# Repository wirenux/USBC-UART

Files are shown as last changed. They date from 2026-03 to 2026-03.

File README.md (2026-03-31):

# USB-C to UART Bridge

A simple project to convert a traditional USB-B UART bridge schematic to a modern **USB-C** interface.

---

## PCB & 3D

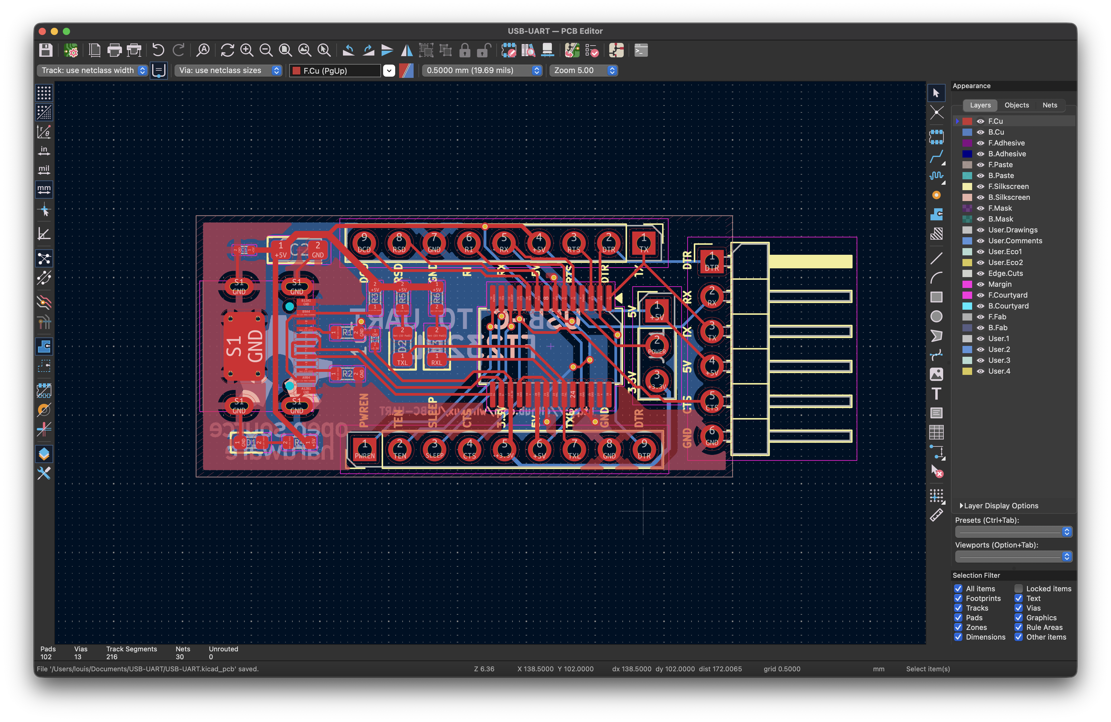
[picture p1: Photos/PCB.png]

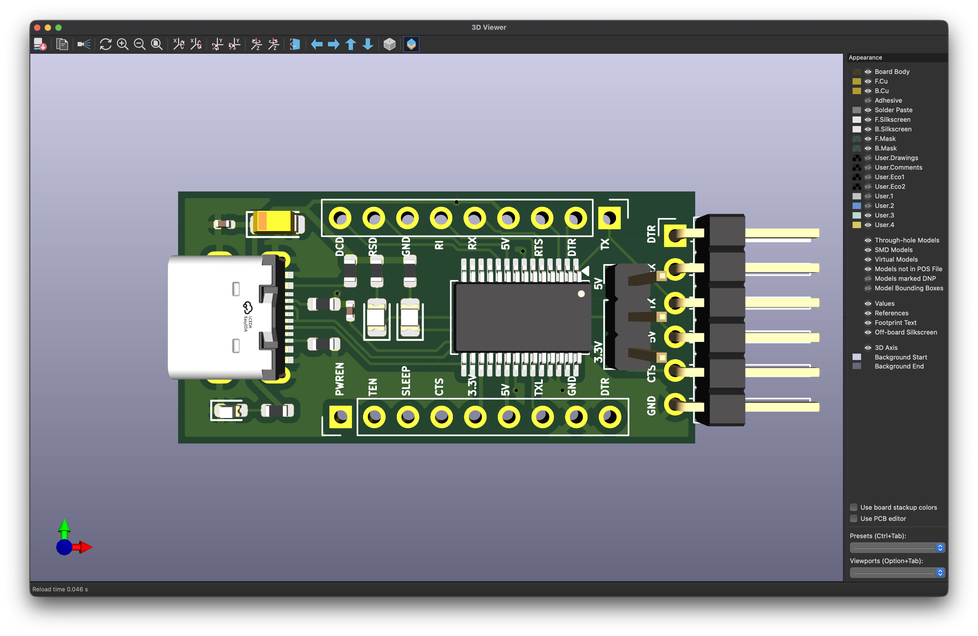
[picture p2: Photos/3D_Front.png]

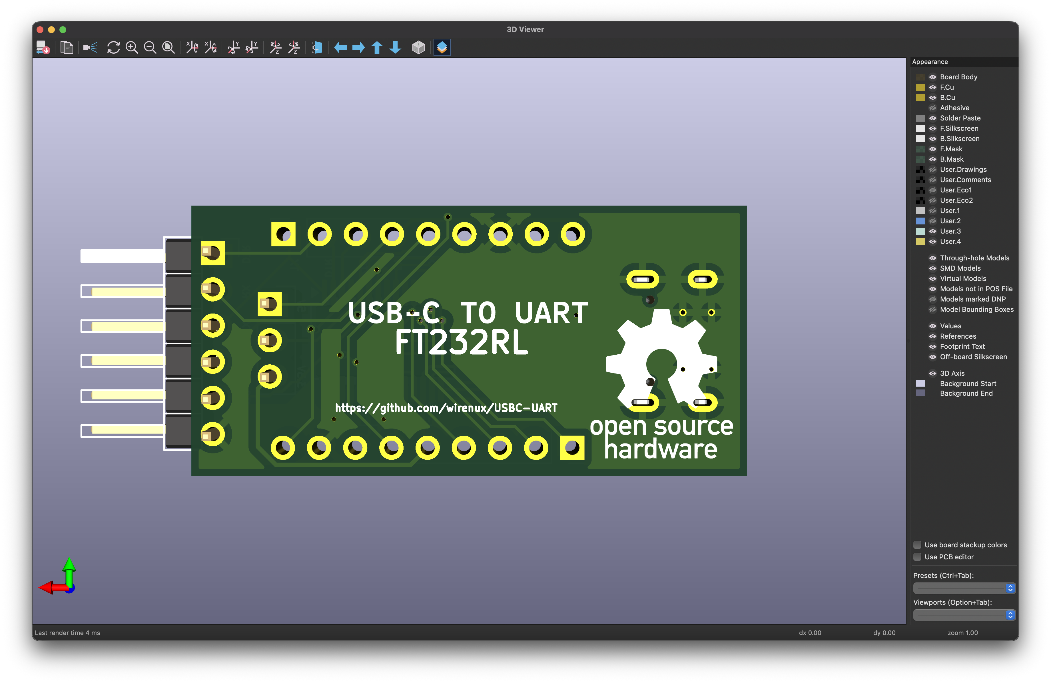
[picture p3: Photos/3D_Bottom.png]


## CC Resistors

For the device to work with **USB-C to USB-C cables**, you must add two resistors to the configuration pins:

* **CC1 (Pin A5):** Connect a **5.1kΩ** resistor to **GND**.
* **CC2 (Pin B5):** Connect a **5.1kΩ** resistor to **GND**.

---

## Schematic

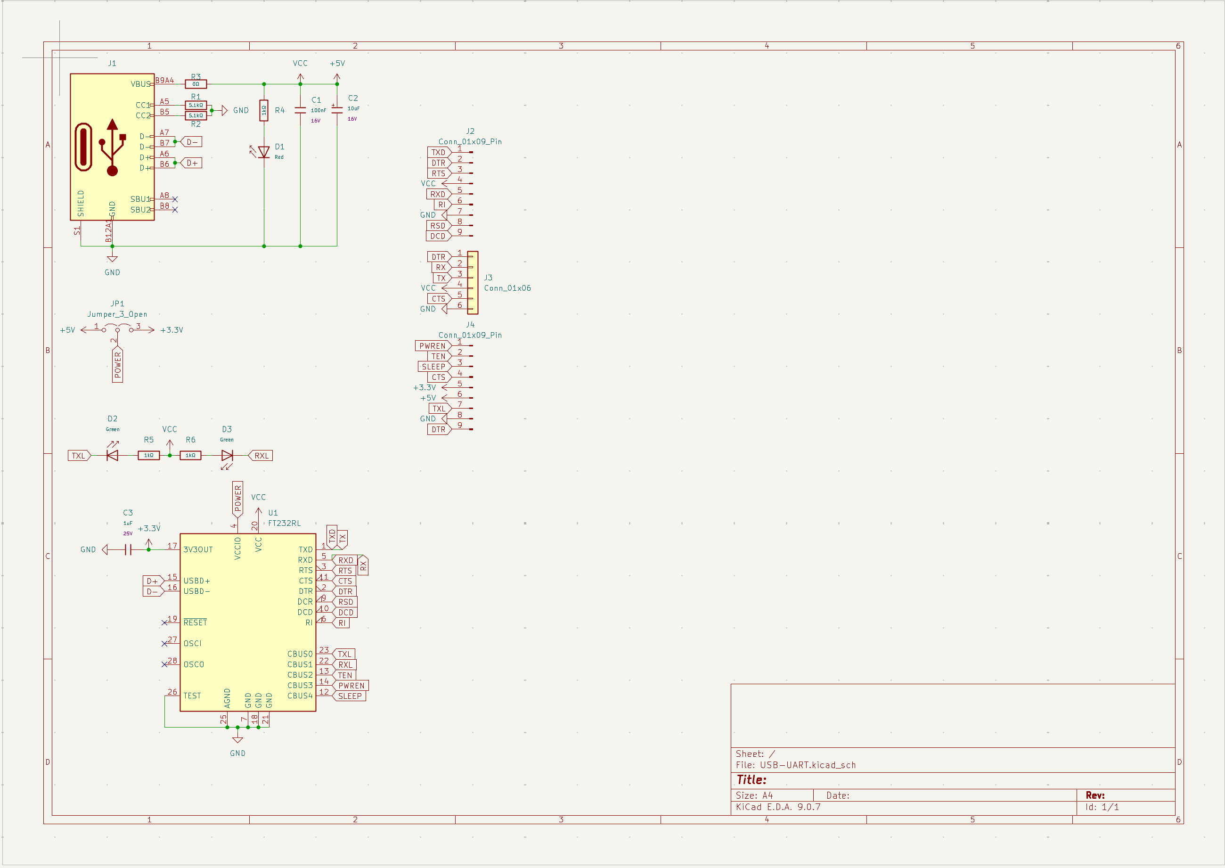
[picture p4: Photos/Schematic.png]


---

## License

This project is under [MIT](./LICENSE) license.

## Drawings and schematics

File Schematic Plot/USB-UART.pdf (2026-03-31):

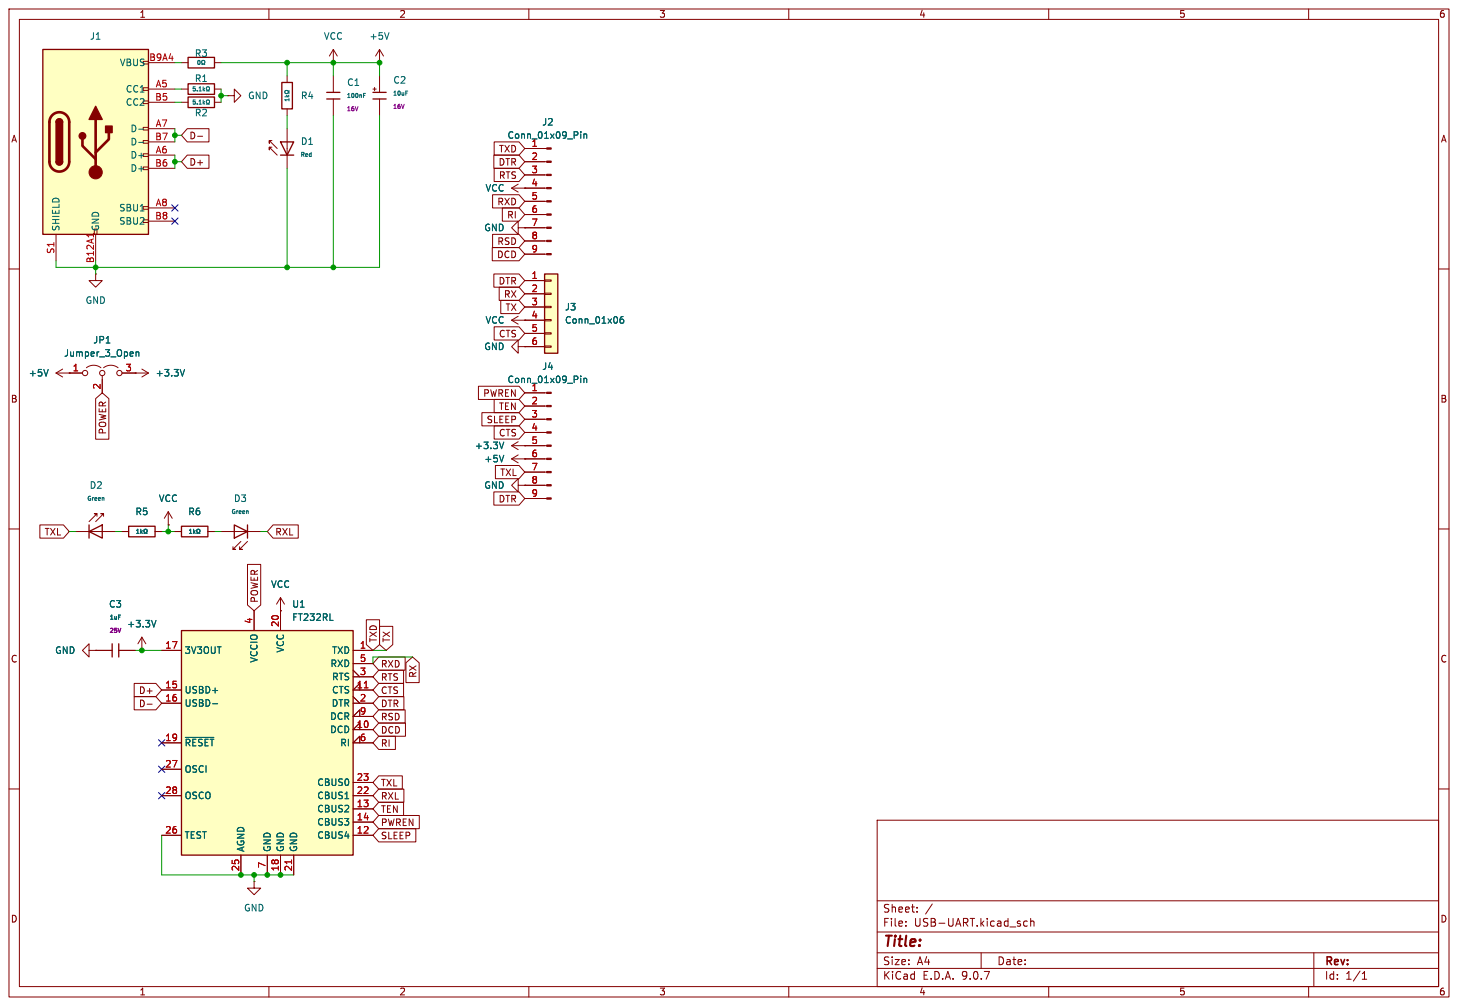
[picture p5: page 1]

Id: 1/1 Title: File: USB-UART.kicad_sch Sheet: / D2

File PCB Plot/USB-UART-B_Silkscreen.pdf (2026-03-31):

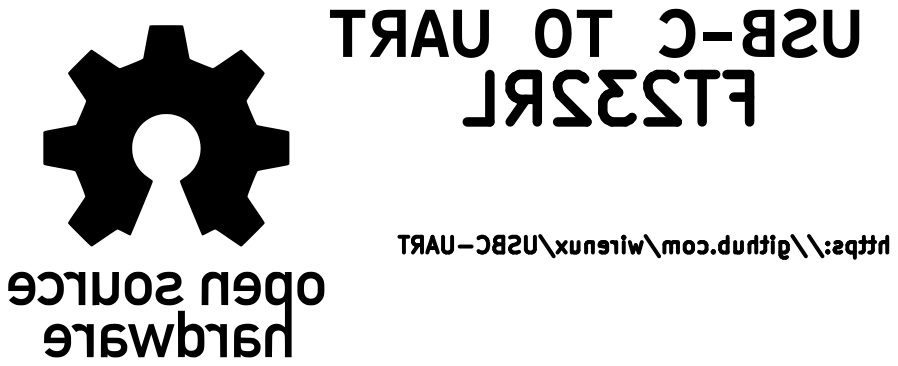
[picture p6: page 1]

https://github.com/wirenux/USBC-UART FT232RL

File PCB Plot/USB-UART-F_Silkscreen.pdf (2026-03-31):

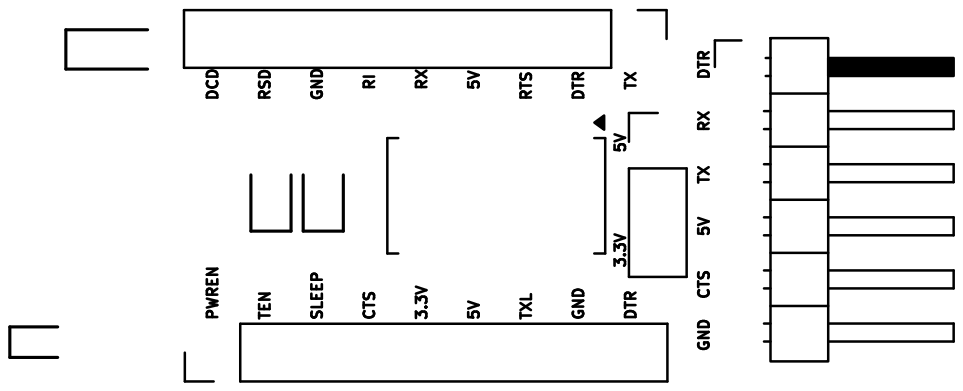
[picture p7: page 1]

5V DCD RTSDTR RX TXL TX DTR RX 5V SLEEP CTS 5V DTRTX CTS 3.3V 3.3V GND GNDPWREN TEN RI 5V RSD GND

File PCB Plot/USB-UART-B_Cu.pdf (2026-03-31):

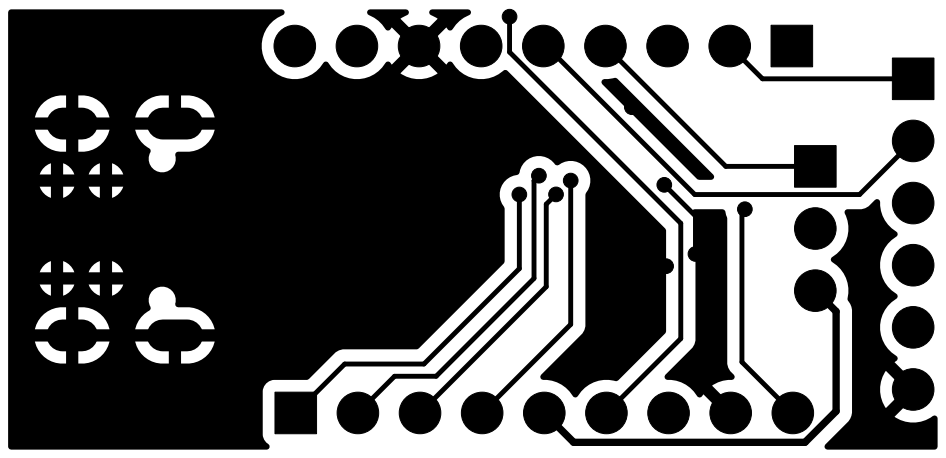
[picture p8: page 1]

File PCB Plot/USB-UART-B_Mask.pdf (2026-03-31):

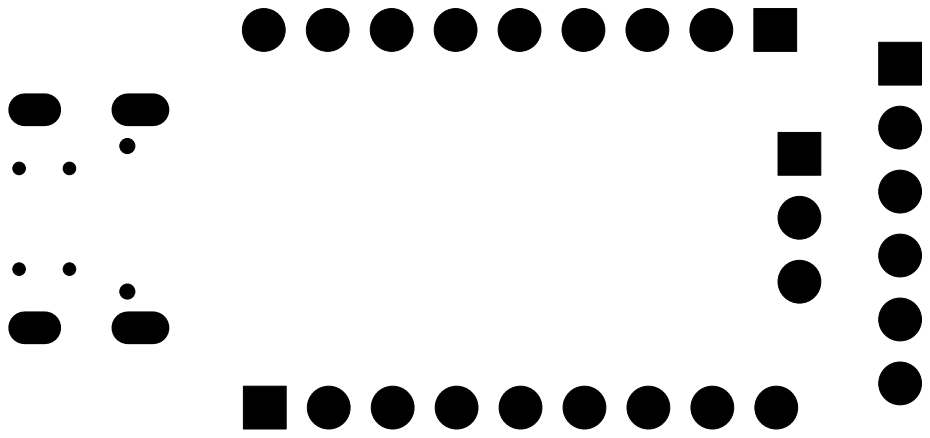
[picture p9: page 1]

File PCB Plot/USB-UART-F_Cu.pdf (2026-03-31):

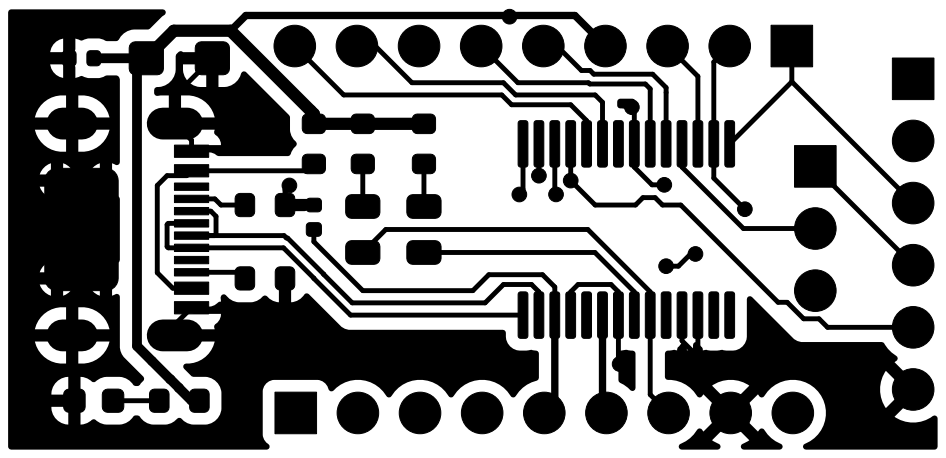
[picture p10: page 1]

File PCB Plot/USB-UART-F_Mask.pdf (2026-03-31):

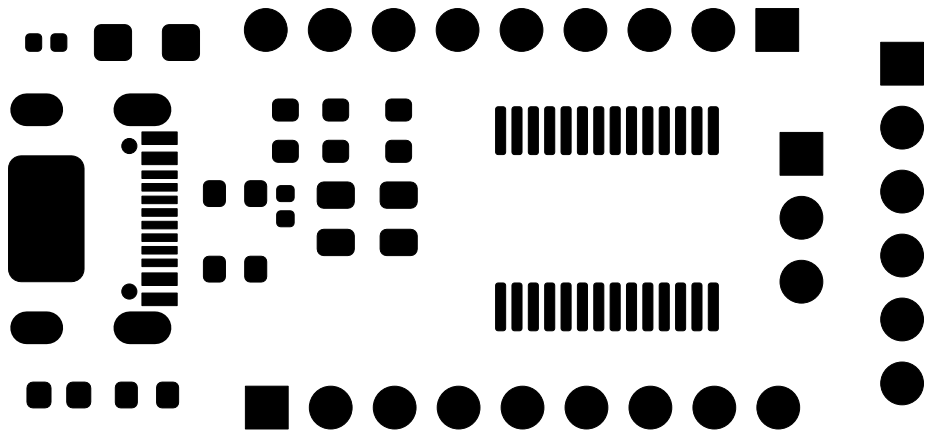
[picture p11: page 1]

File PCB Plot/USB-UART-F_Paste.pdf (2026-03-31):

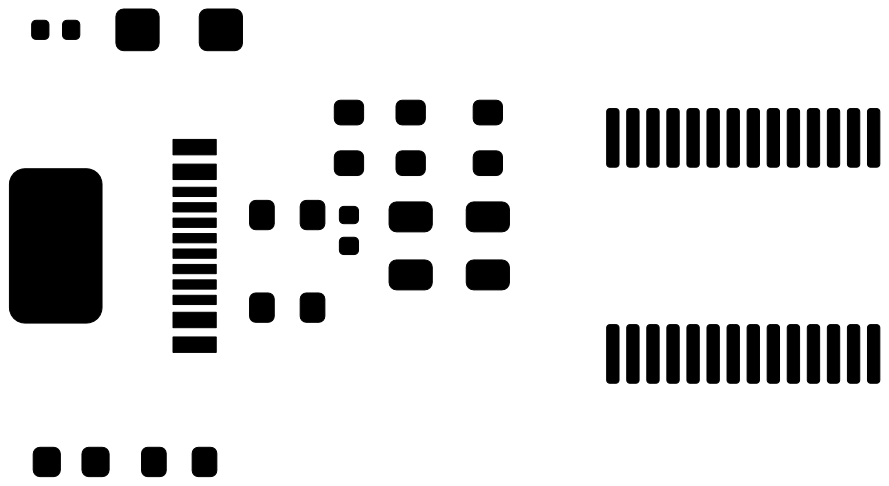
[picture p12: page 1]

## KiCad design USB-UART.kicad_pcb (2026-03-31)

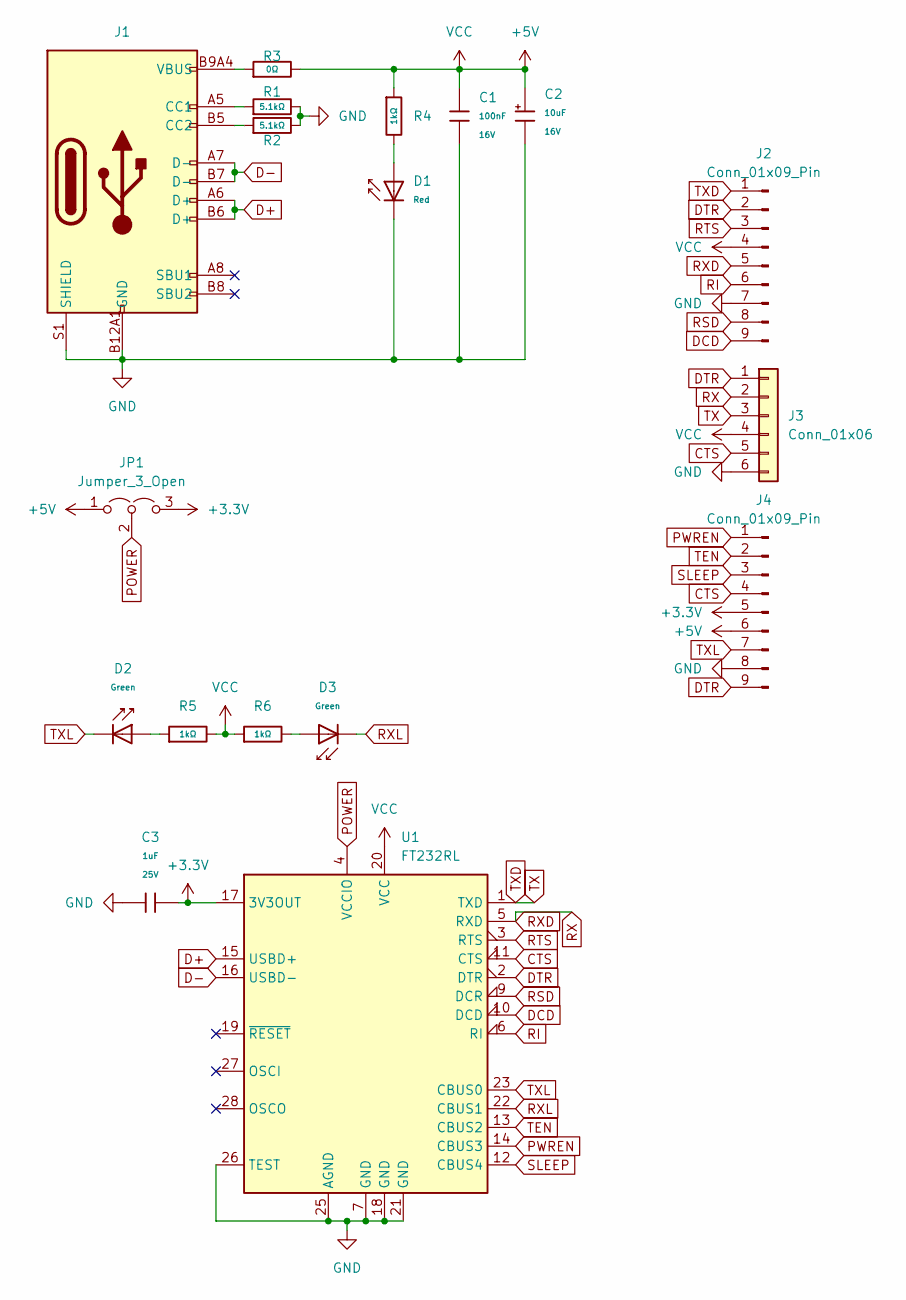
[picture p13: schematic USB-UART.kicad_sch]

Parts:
C1: 100nF; C_0402; Voltage Rated 16V; Tolerance ±10%; Part CL05B104KO5NNNC; LCSC C1525
C2: 10uF; C_CASE-A-3216-18(mm); Tolerance ±10%; Rated Voltage 16V; Part TAJA106K016RNJ; LCSC C7171
C3: 1uF; C_0402; Voltage Rated 25V; Tolerance ±10%; Part CL05A105KA5NQNC; LCSC C52923
D1: Red; D_0603; Part KT-0603R; LCSC C2286
D2, D3: Green; D_0805; Part KT-0805G; LCSC C2297
J1: Connector, USB-TYPE-C-16P; TYPE-C-SMD_HX-TYPE-C-16PIN; LCSC C2927039
J2, J4: Conn_01x09_Pin; PinHeader_1x09_P2.54mm_Vertical
J3: Conn_01x06; PinHeader_1x06_P2.54mm_Horizontal
JP1: Jumper_3_Open; PinHeader_1x03_P2.54mm_Vertical
R1, R2: 5.1kΩ; R_0603; Overload Voltage (Max) 75V; Tolerance ±1%; Part 0603WAF5101T5E; LCSC C23186
R3: 0Ω; R_0603; Overload Voltage (Max) 75V; Tolerance ±1%; Part 0603WAF0000T5E; LCSC C21189
R4, R5, R6: 1kΩ; R_0603; Overload Voltage (Max) 75V; Tolerance ±1%; Part 0603WAF1001T5E; LCSC C21190
U1: FT232RL; SSOP-28_5.3x10.2mm_P0.65mm

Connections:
+3.3V: C3.2, J4.5, JP1.3 (B), U1.17 (3V3OUT)
+5V: C1.1, C2.1, J2.4, J3.4, J4.6, JP1.1 (A), R3.2, R4.1, R5.2, R6.1, U1.20 (VCC)
CTS: J3.5, J4.4, U1.11 (CTS)
D+: J1.A6 (D+), J1.B6 (D+), U1.15 (USBD+)
D-: J1.A7 (D-), J1.B7 (D-), U1.16 (USBD-)
DCD: J2.9, U1.10 (DCD)
DTR: J2.2, J3.1, J4.9, U1.2 (DTR)
GND: C1.2, C2.2, C3.1, D1.1, J1.A12B1 (GND), J1.B12A1 (GND), J1.S1 (SHIELD), J2.7, J3.6, J4.8, R1.2, R2.2, U1.7 (GND), U1.18 (GND), U1.21 (GND), U1.25 (AGND), U1.26 (TEST)
unnamed: D1.2, R4.2
unnamed: D2.2, R5.1
unnamed: D3.2, R6.2
unnamed: J1.A5 (CC1), R1.1
unnamed: J1.B5 (CC2), R2.1
unnamed: J1.A9B4 (VBUS), J1.B9A4 (VBUS), R3.1
POWER: JP1.2 (C), U1.4 (VCCIO)
PWREN: J4.1, U1.14 (CBUS3)
RI: J2.6, U1.6 (RI)
RSD: J2.8, U1.9 (DCR)
RTS: J2.3, U1.3 (RTS)
RX: J2.5, J3.2, U1.5 (RXD)
RXL: D3.1, U1.22 (CBUS1)
SLEEP: J4.3, U1.12 (CBUS4)
TEN: J4.2, U1.13 (CBUS2)
TX: J2.1, J3.3, U1.1 (TXD)
TXL: D2.1, J4.7, U1.23 (CBUS0)

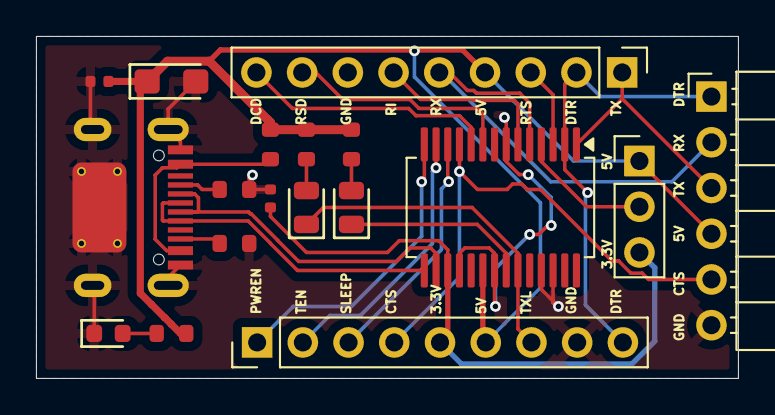
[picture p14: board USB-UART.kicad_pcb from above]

Board: 2 copper layers, 39.0 x 19.0 mm, 18 parts (0 on the bottom side), 25 nets.

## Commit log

2026-03-31 add: github link
    [USB-UART.kicad_pcb]
2026-03-31 add: README.md + LICENSE
    [USB-UART.kicad_pcb]
